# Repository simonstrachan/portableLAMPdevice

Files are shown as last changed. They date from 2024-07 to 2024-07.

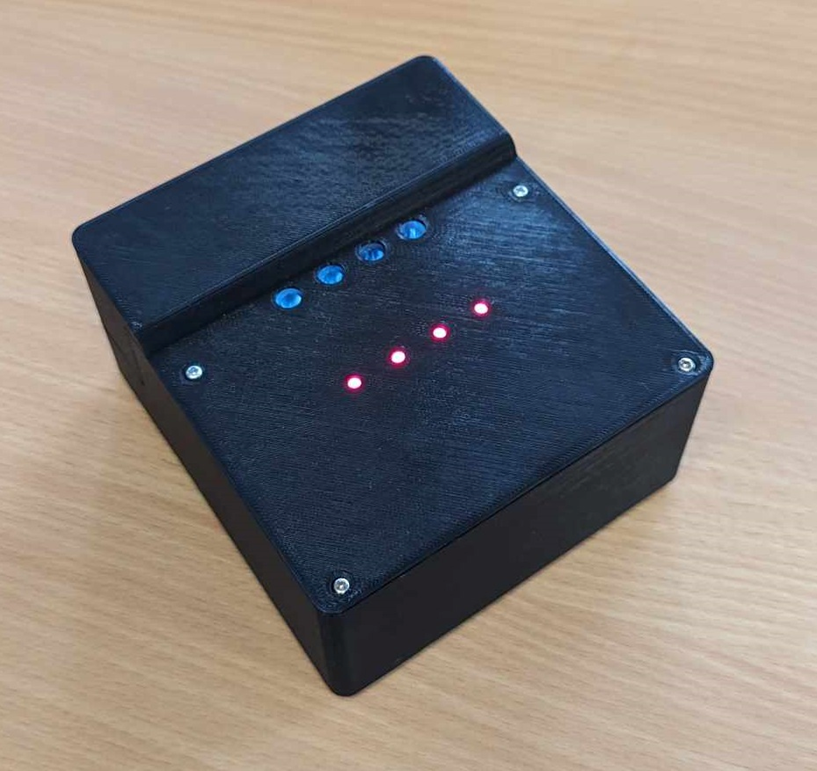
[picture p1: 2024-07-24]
Images/LAMP device.png

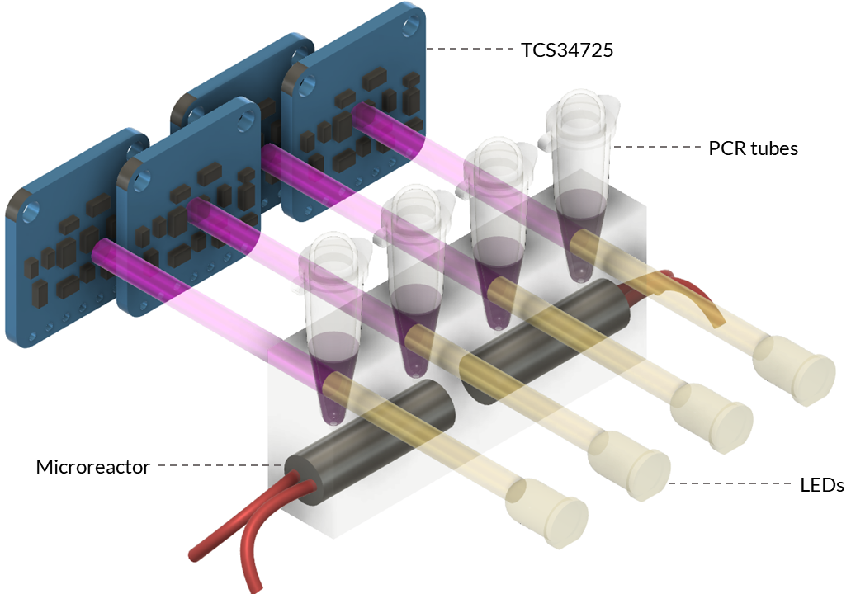
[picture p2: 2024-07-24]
Images/Visualisation.png

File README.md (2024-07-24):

# LAMP Device for PhD Research

## Overview
This repository contains the designs, schematics, 3D models, and documentation for the LAMP (Loop-mediated Isothermal Amplification) device developed as part of my PhD research at Griffith University. The device is designed for rapid, on-site molecular diagnostics, particularly for detecting sugarcane diseases.

https://www.mdpi.com/2072-666X/14/11/2101

## Features
- **Portable Design:** Compact and lightweight for field use.
- **Rapid Diagnostics:** Utilizes LAMP technology for fast and accurate detection.
- **User-Friendly Interface:** Simple controls and display for ease of use.

## Contents
- **Designs:** Schematics and PCB designs.
- **Mechanical:** Mechanical design files.
- **3D Models:** Detailed models for various components.
- **Documentation:** User manuals, technical specifications, and development notes.

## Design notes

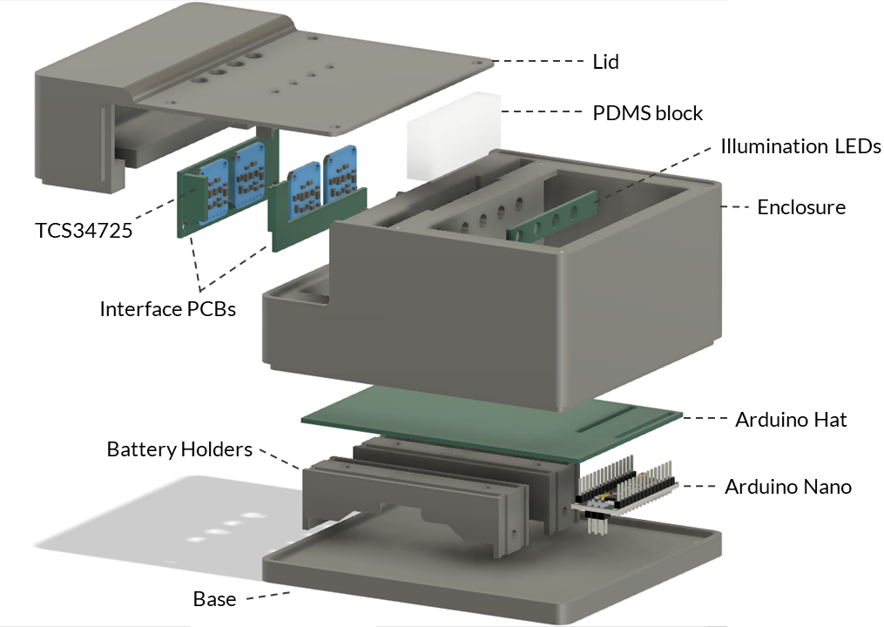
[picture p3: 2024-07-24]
Images/ExplodedView.png

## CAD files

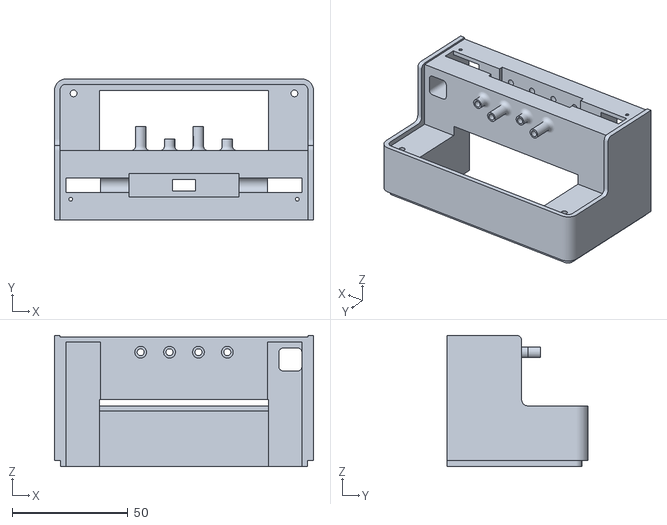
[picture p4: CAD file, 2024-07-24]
Mechanical/STL/Adj_PDMSholder.stl
112.0 x 61.0 x 56.8

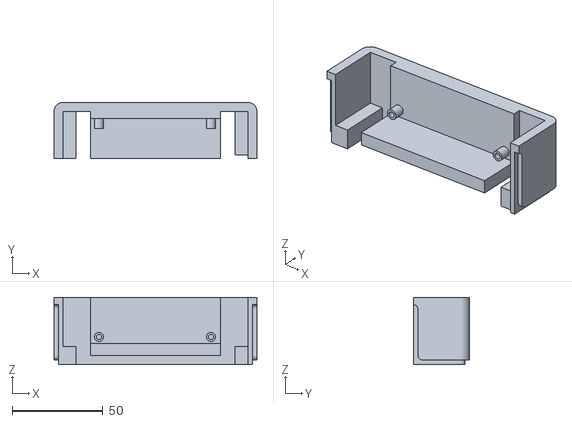
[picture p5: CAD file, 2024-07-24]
Mechanical/STL/Adj_TCScradle.stl
112.0 x 31.0 x 37.0

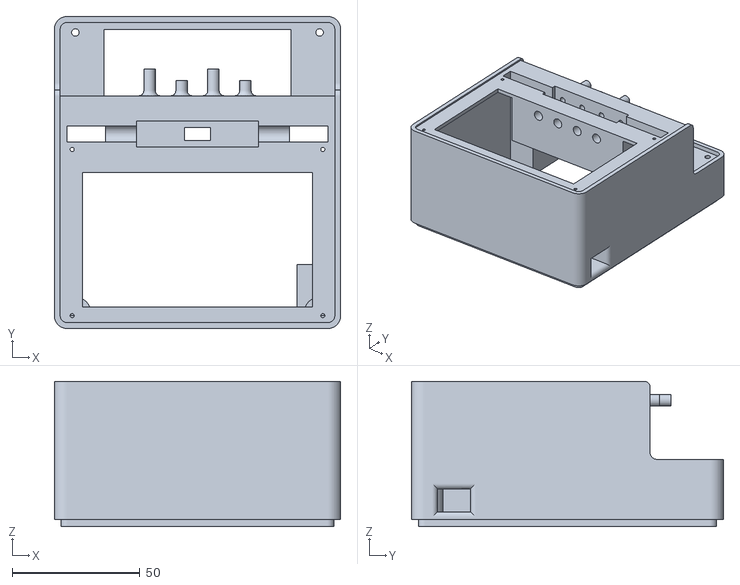
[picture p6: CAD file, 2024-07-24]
Mechanical/STL/Base_v5.stl
112.0 x 122.0 x 56.8

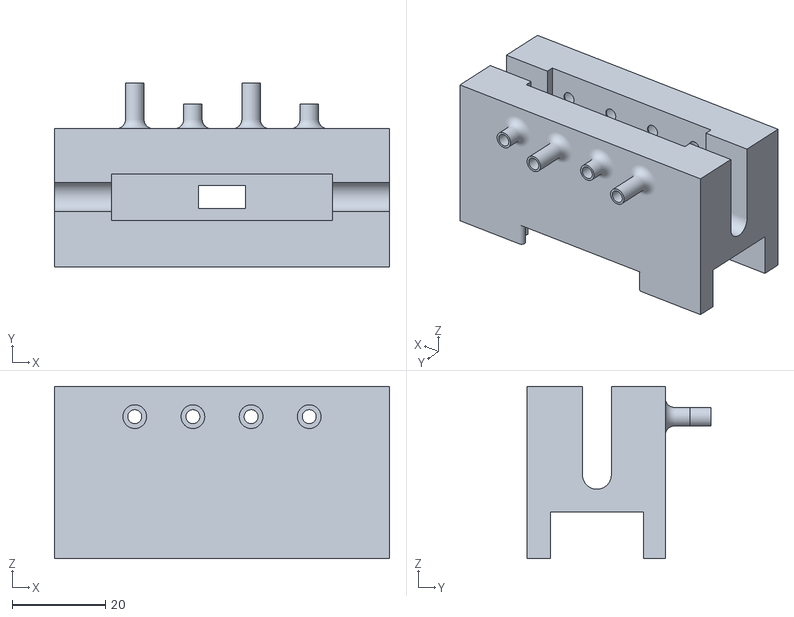
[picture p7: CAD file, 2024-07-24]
Mechanical/STL/PDMSholder.stl
72.0 x 39.5 x 37.0

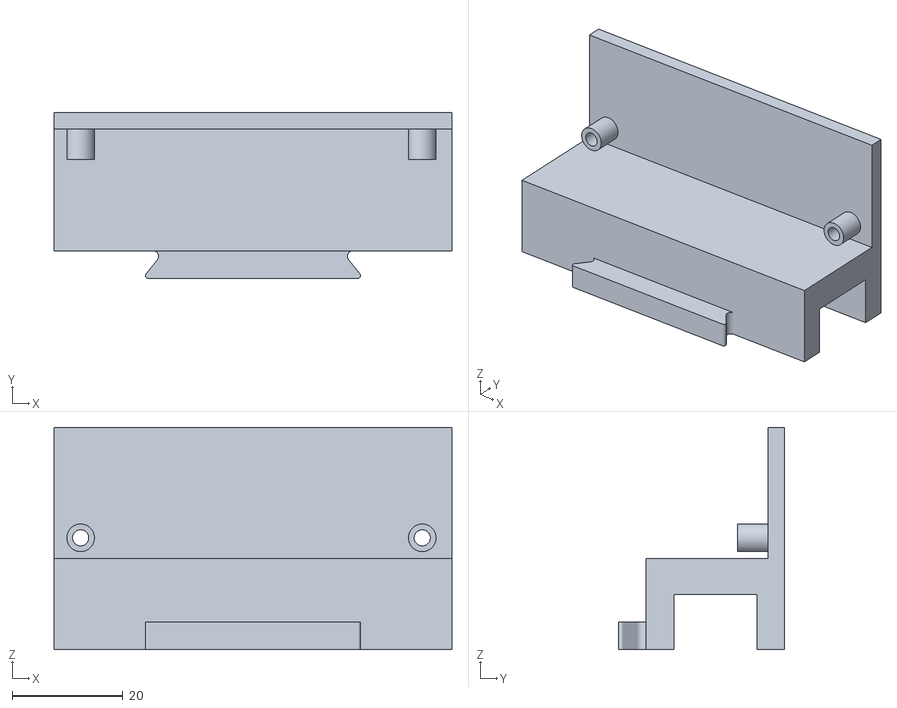
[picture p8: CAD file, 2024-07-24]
Mechanical/STL/TCScradle.stl
72.0 x 30.0 x 40.2

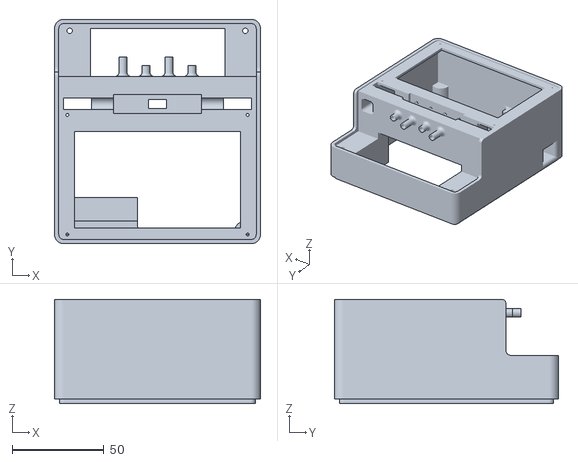
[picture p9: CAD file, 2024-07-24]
Mechanical/STL/Box_PDMSholder.stl
112.0 x 122.0 x 56.8

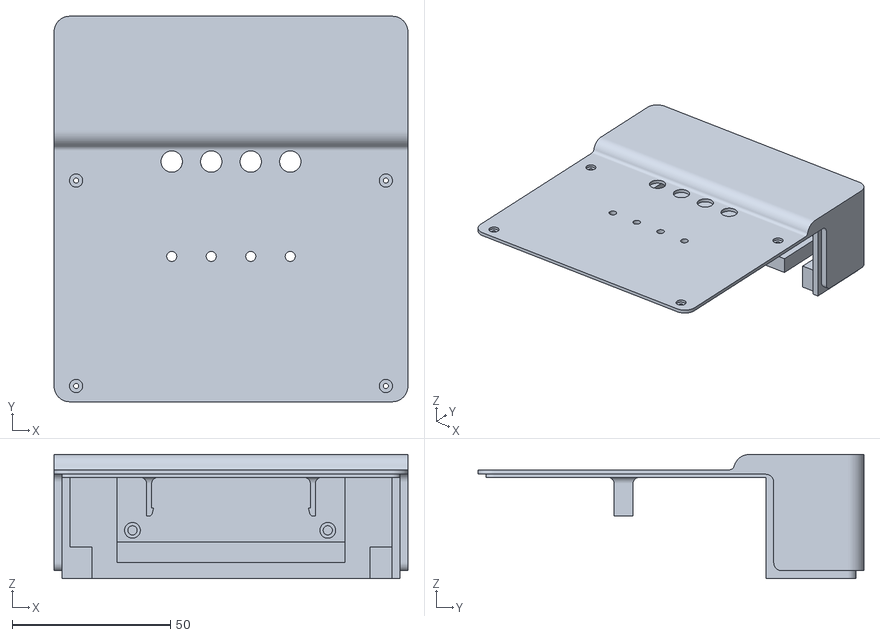
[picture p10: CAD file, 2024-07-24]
Mechanical/STL/Box_TCScradle.stl
112.0 x 122.0 x 39.2

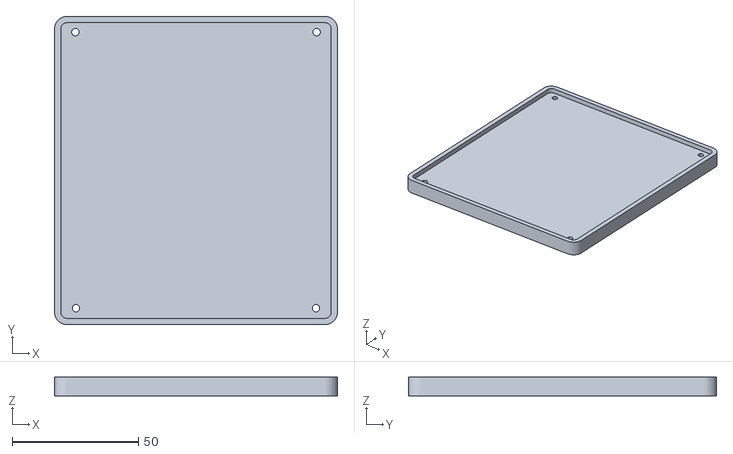
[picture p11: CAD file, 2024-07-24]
Mechanical/STL/Box_base.stl
112.0 x 122.0 x 7.50

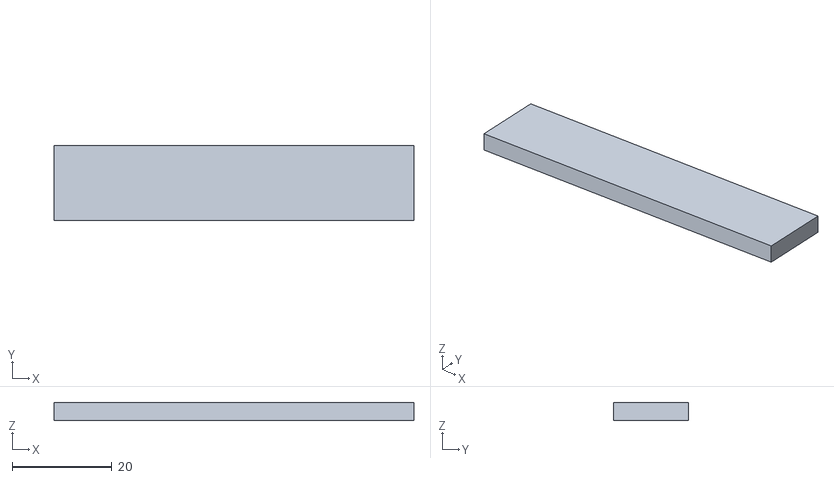
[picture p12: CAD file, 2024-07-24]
Mechanical/STL/Box stool.stl
72.0 x 15.0 x 3.70

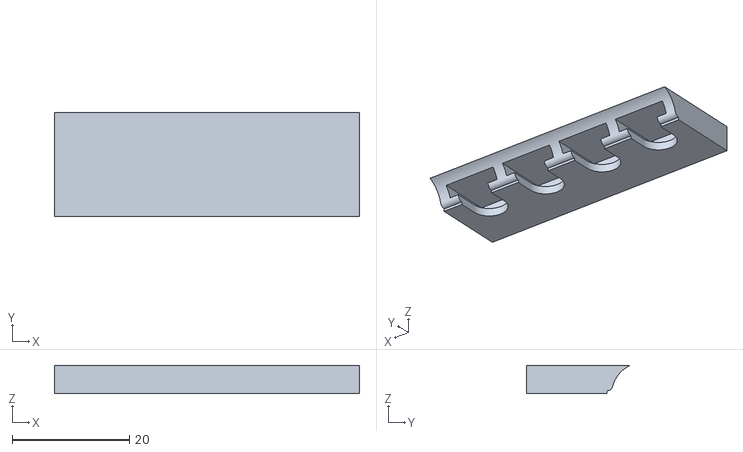
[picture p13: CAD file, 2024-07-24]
Mechanical/STL/Lid.stl
52.0 x 17.7 x 4.85

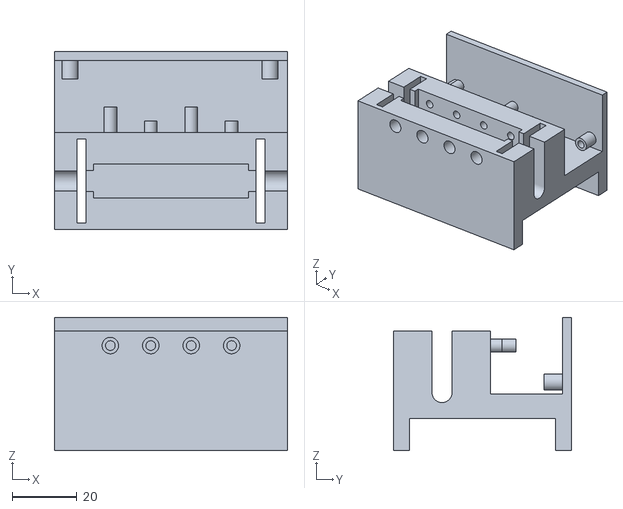
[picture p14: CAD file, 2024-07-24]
Mechanical/STL/V5 - DetectionBox .stl
72.0 x 55.0 x 41.2

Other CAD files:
Mechanical/CAD/Portable LAMP device.f3z

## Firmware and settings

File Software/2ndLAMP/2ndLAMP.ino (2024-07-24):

#include <PID_v1.h>             //PID library
#include <Wire.h>               //I2C library
#include "Adafruit_TCS34725.h"  //RGB color sensor library

//LAMP values
const double targetTemp = 87.5;
const float endTime = 30;

//Initialising Pins
#define fetPin 11
#define thermoPin A0

//Time Variables
uint32_t timer, timeMinutes, timeSeconds, elapsedTime, currentMillis, previousMillis, prev_timeSeconds, startTime;
uint16_t RGBinterval = 700;  //Time in milliseconds

//Temperature Variables
const uint32_t thermoOhm = 100000;       //NTC nominal resistance
const int8_t thermoOhmTemp = 25;         //NTC temperature for nominal resistance
const uint16_t thermoBeta = 3950;        //Beta for NTC
const uint32_t seriesResistor = 100000;  //Value of R1
const uint8_t numSamples = 250;
int16_t samples[numSamples];
double adcvalue, thermoValue, set, adj_set, steinhart;

//RGB -> XYZ matrices
const float patchMatrix[3][3] = { { 0.004471237, 0.003999354, -0.0001078278 }, { 0.000305326, 0.01103072, -0.0032857488 }, { -0.0022756, -0.00100645, 0.012742875 } };
float rgb[3], XYZ[3];
Adafruit_TCS34725 tcs[] = { Adafruit_TCS34725(TCS34725_INTEGRATIONTIME_614MS, TCS34725_GAIN_1X),
                            Adafruit_TCS34725(TCS34725_INTEGRATIONTIME_614MS, TCS34725_GAIN_1X),
                            Adafruit_TCS34725(TCS34725_INTEGRATIONTIME_614MS, TCS34725_GAIN_1X),
                            Adafruit_TCS34725(TCS34725_INTEGRATIONTIME_614MS, TCS34725_GAIN_1X) };
const uint8_t TCScount = 4;
#define TCAADDR 0x70

//Color Index Value variables
bool initialCIVfound[] = { false, false, false, false };
float initialCIV[TCScount];
uint8_t positiveArray[TCScount];
float CIV, zeroCIV = 0;

// Moving average Variables
const uint8_t window_size = 15;
uint8_t index = 0;
float sum, averaged = 0;
float readings[window_size];

//Testing positive variables
const uint8_t numReadings = 20;
float pos_readings[TCScount][numReadings];
float currentReadings[TCScount];
int pos_count[] = { 0, 0, 0, 0 };
uint8_t currentIndex = 0;
bool positive = false;

//Other Variables
uint8_t i, inChar;
bool ready, running = false;
float printArray[40];

//PID initialisation
const double Kp = 48;
const double Ki = 1.352113;
const double Kd = 426;
PID myPID(&steinhart, &set, &targetTemp, Kp, Ki, Kd, DIRECT);

void setup(void) {
  Serial.begin(9600);
  Wire.begin();
  initTCS();

  analogReference(EXTERNAL);  //3V3 AREF

  myPID.SetMode(AUTOMATIC);
  for (int i = 3; i <= 10; i++) {
    pinMode(i, OUTPUT);
    if (i % 2 == 1) {
      digitalWrite(i, HIGH);
    }
  }
  pinMode(fetPin, OUTPUT);

  startTime = millis();
}

void loop(void) {
  if (Serial.available() > 0) {
    inChar = Serial.read();
  }
  //Press 's' to start heating and 'a' to start experiment
  if (!running && inChar == 'a') {
    running = true;
    startTime = millis();
    prev_timeSeconds = 0;
  } else if (!ready && inChar == 's') {
    ready = true;
    startTime = millis();
    prev_timeSeconds = 0;
  }

  if (ready) {
    //Read NTC and update temperature value
    steinhartCalc();
    //Use PID to set FET PWM value
    myPID.Compute();
    adj_set = set / 4;
    analogWrite(fetPin, adj_set);
  }



  if (running) {
    //Only get RGB data if the integration time has passed
    unsigned long currentMillis = millis();
    if (currentMillis - previousMillis >= RGBinterval) {
      for (int i = 0; i < TCScount; i++) {
        RGBsensor(i);
      }
      previousMillis = currentMillis;
    }
    for (int i = 0; i < TCScount; i++) {
      if (positiveArray[i] == 1) {
        int pin = 3 + i;
        digitalWrite(pin - 1, LOW);
        digitalWrite(pin, HIGH);
      }
    }
  }

  //Timer details
  printTimer();

  //Check if time is up
  if (timer >= (endTime * 60)) {
    endScreen();
  }
}

void initTCS() {
  for (int i = 0; i < TCScount; i++) {
    tcaselect(i);
    if (tcs[i].begin()) {
      Serial.println("Found sensor ");
    } else {
      Serial.println("No Sensor Found");
      while (true)
        ;
    }
  }
}

void tcaselect(uint8_t bus) {
  if (bus > TCScount) return;
  Wire.beginTransmission(TCAADDR);
  Wire.write(1 << (bus + 4));
  Wire.endTransmission();
}

//Calculate NTC temperature
void steinhartCalc() {
  //Read NTC and average multiple samples for stability
  for (i = 0; i < numSamples; i++) {
    samples[i] = analogRead(thermoPin);
  }
  adcvalue = 0;

  //averaging samples
  for (i = 0; i < numSamples; i++) {
    adcvalue += samples[i];
  }
  adcvalue /= numSamples;

  /*            Math
     Voltage divider: Vo=Vcc(R2/R1+R2)
     ADC value = vo*1023/Varef
     ADC value = Vcc(R2/R1+R2)*1023/Varef
     Varef=Vcc
     ADC value= (R2/R1+R2)*1023
     R2 = - (R1 * ADC value)/(ADC value - 1023)
  */
  thermoValue = -(seriesResistor * adcvalue) / (adcvalue - 1023);

  /*   Steinhart-Hart Equation
     1/T = (1/To) + 1/B * ln(R/Ro)
  */
  steinhart = thermoValue / thermoOhm;          // (R/Ro)
  steinhart = log(steinhart);                   // ln(R/Ro)
  steinhart /= thermoBeta;                      // 1/B * ln(R/Ro)
  steinhart += 1.0 / (thermoOhmTemp + 273.15);  // + (1/To)
  steinhart = 1.0 / steinhart;                  // Invert
  steinhart -= 273.15;                          // convert absolute temp to C
}

void printTimer() {
  //Print time elapsed
  elapsedTime = millis() - startTime;
  timer = elapsedTime / 1000;
  timeMinutes = timer / 60;
  timeSeconds = timer % 60;
  if (timer > prev_timeSeconds) {
    Serial.print(timeMinutes);
    Serial.print("m ");
    Serial.print(timeSeconds);
    Serial.print("s, ");
    Serial.print(steinhart - (targetTemp - 65));
    Serial.print(", ");
    Serial.print(adj_set);
    Serial.print(", ");
    for (int i = 0; i < 40; i++) {
      if (i < 39) {
        Serial.print(printArray[i]);
        Serial.print(", ");
      } else {
        Serial.println(printArray[i]);
      }
    }
    prev_timeSeconds = timer;
  }
}

void endScreen() {
  //Tell user completion and turn both lights on
  Serial.print("Process Complete!");
  delay(500);
  analogWrite(fetPin, 0);
  while (1) {}
}

void RGBsensor(uint8_t sensorNum) {
  tcaselect(sensorNum);

  //RGB
  rgb[0] = tcs[sensorNum].read16(TCS34725_RDATAL);
  rgb[1] = tcs[sensorNum].read16(TCS34725_GDATAL);
  rgb[2] = tcs[sensorNum].read16(TCS34725_BDATAL);

  for (int i = 0; i < 3; i++) {
    printArray[sensorNum * 10 + i] = rgb[i];
  }

  //XYZ and CIV
  for (int i = 0; i < 3; i++) {
    for (int j = 0; j < 3; j++) {
      XYZ[i] += patchMatrix[i][j] * rgb[j];
    }
    if (i == 1) {
      CIV = XYZ[i];
    }
    if (i == 2) {
      CIV -= XYZ[i];
    }
    printArray[sensorNum * 10 + i + 3] = XYZ[i];
    XYZ[i] = 0;
  }       
  printArray[sensorNum * 10 + 6] = CIV;

  //Normalise CIV
  if (!initialCIVfound[sensorNum]) {
    initialCIV[sensorNum] = CIV;
    initialCIVfound[sensorNum] = true;
  }
  zeroCIV = CIV - initialCIV[sensorNum];
  printArray[sensorNum * 10 + 7] = zeroCIV;

  //Determine moving average
  sum -= readings[index];             //removes oldest entry
  readings[index] = zeroCIV;          //Add newest to window
  sum += zeroCIV;                     //Add newest to sum
  index = (index + 1) % window_size;  //Increment the index or wrap to 0
  averaged = sum / window_size;
  printArray[sensorNum * 10 + 8] = averaged;

  //Check for increase in CIV
  uint8_t previousIndex = currentIndex % numReadings;
  currentReadings[sensorNum] = averaged;

  float diff = currentReadings[sensorNum] - (pos_readings[sensorNum][previousIndex] + 0.5) / numReadings;

  if (timeMinutes >= 5 && diff > 0) {
    pos_count[sensorNum] = 1 + pos_count[sensorNum]; 
  } else {
    pos_count[sensorNum] = 0;
  }
  
  if (pos_count[sensorNum] >= 3) {
    positiveArray[sensorNum] = 1;
    printArray[sensorNum * 10 + 9] = 1;
  } else {
    printArray[sensorNum * 10 + 9] = 0;
  }
  pos_readings[sensorNum][currentIndex] = currentReadings[sensorNum];
  currentIndex = (currentIndex + 1) % numReadings;
}

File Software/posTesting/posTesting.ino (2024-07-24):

const uint8_t numReadings = 10;
float readings[2][numReadings];
float currentReadings[2];
uint8_t currentIndex, j = 0;
uint8_t count[] = { 0, 0 };
uint16_t interval = 1000;
bool readingsInc = false;

float sensorValue1[] = { 3.788, 3.791, 3.795, 3.799, 3.802, 3.808, 3.812, 3.814, 3.817, 3.82, 3.822, 3.828, 3.832, 3.836, 3.84, 3.844, 3.85, 3.856, 3.86, 3.866, 3.871, 3.877, 3.88, 3.891, 3.899 };
float sensorValue2[] = { 4.788, 4.791, 4.795, 4.799, 4.802, 4.808, 4.812, 4.814, 4.817, 4.82, 4.822, 4.828, 4.832, 4.836, 4.84, 4.844, 4.85, 4.856, 4.86, 4.866, 4.871, 4.877, 4.88, 4.891, 4.899 };

void setup() {
  // put your setup code here, to run once:
  Serial.begin(9600);
  Serial.println("Current, Readings 1, Readings 2, Previous, Count 1, Count 2, P/N 1, P/N 2");
}

void loop() {
  // put your main code here, to run repeatedly:
  int previousIndex = currentIndex % numReadings;
  for (int i = 0; i < 2; i++) {
    if (i == 0) {
      currentReadings[i] = sensorValue1[j];
    } else {
      currentReadings[i] = sensorValue2[j];
    }
    if (readingsInc) {
      if (((currentReadings[i] - readings[i][previousIndex]) / numReadings > 0)) {
        count[i]++;
      } else {
        count[i] = 0;
      }
    }
    readings[i][currentIndex] = currentReadings[i];
  }


  Serial.print(currentIndex);
  Serial.print(", ");
  Serial.print(readings[0][currentIndex]);
  Serial.print(", ");
  Serial.print(readings[1][currentIndex]);
  Serial.print(", ");
  Serial.print(previousIndex);
  Serial.print(", ");
  Serial.print(count[0]);
  Serial.print(", ");
  Serial.print(count[1]);
  Serial.print(", ");
  for (int i = 0; i < 2; i++) {
    if (count[i] >= 3) {
      if (i == 0) {
        Serial.print("1");
        Serial.print(", ");
      } else {
        Serial.println("1");
      }
    } else {
      if (i == 0) {
        Serial.print("0");
        Serial.print(", ");
      } else {
        Serial.println("0");
      }
    }
  }
  if (!readingsInc && currentIndex == numReadings - 1) {
    readingsInc = true;
    Serial.println("Begin readings");
  }
  currentIndex = (currentIndex + 1) % numReadings;

  j++;
  if (j == 24) {
    while (1)
      ;
  }

  //delay(interval);
}
